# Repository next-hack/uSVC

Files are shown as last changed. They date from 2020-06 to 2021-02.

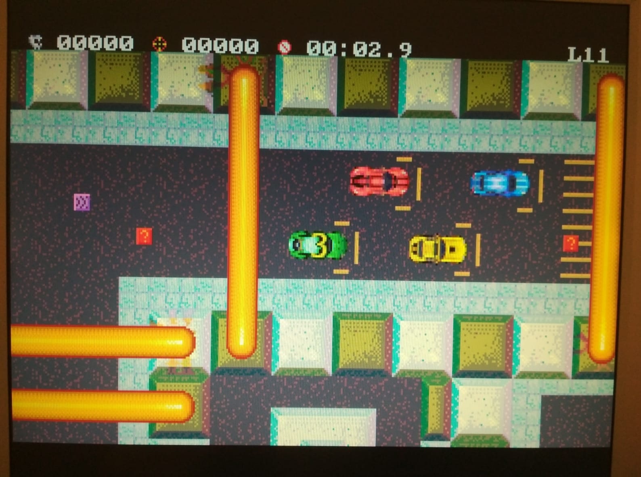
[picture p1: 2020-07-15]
images/Fairplay Race 3.jpg

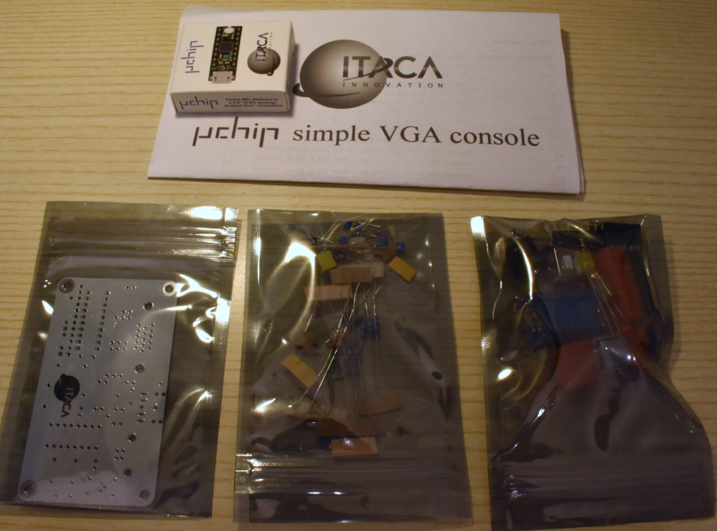
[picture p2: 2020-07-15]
images/Kit contents.png

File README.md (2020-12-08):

# uSVC
uChip Simple VGA Console
An open source, easy to build retro game console!

This project is a very simple VGA console, based on uChip. Games are loaded from the SD card, and you can use standard keyboards or gamepads.

The console is made of few, easy to find and easy to solder components. There is only one SMD component: the micro-SD card reader.

The ATSAMD21 (A 48 MHz Cortex M0+) generates the VGA and audio signals, and provides up to 256 simultaneous colors. There are 3 video modes:
- Bitmapped Mode
- 8 bpp tiled mode
- 4 bpp tiled mode.

Each mode has its own peculiarity. For more information, visit next-hack.com!

You might also want to take a look at:

- The game editor source code: https://github.com/next-hack/uChipGameMapEditor
- Redballs, a Worms-like game: https://github.com/next-hack/uSVC_Redballs
- Fairplay race: https://github.com/next-hack/uSVC_Fairplay-race
- uSVC Tetris: https://github.com/next-hack/uSVC_Tetris

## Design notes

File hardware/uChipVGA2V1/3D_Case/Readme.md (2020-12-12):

3D Case designed by [Stefano Rubini](https://dreamdesigndevelop3d.webnode.it/english/).
Available ".stl" files are:
- Top:     "#55 case no standoff top.stl"
- Bottom:  "#55 case no standoff bottom.stl"

Available ".step" files are:
- Assembled: "case uChipVGA v55.step"

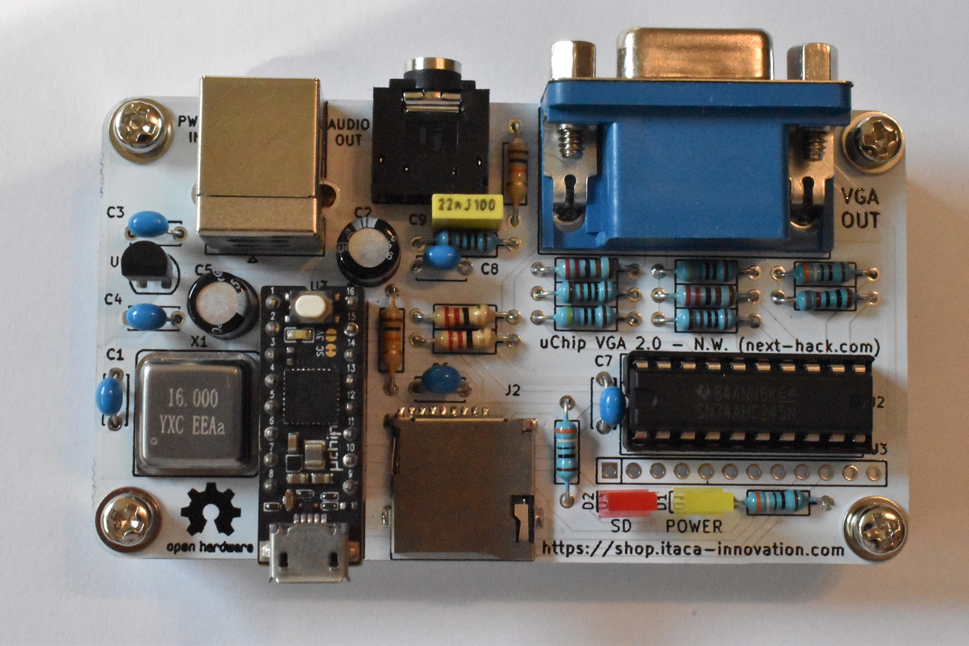
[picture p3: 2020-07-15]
images/uSVC-reduced.jpg

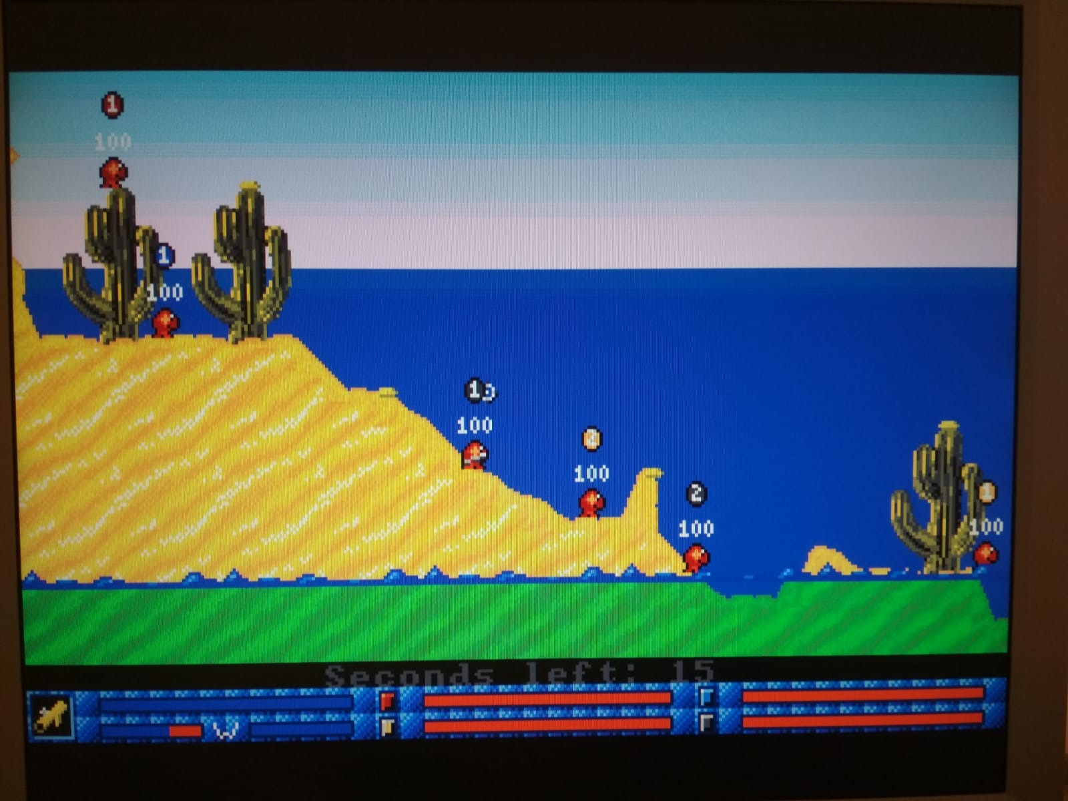
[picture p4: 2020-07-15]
images/redballs3.png

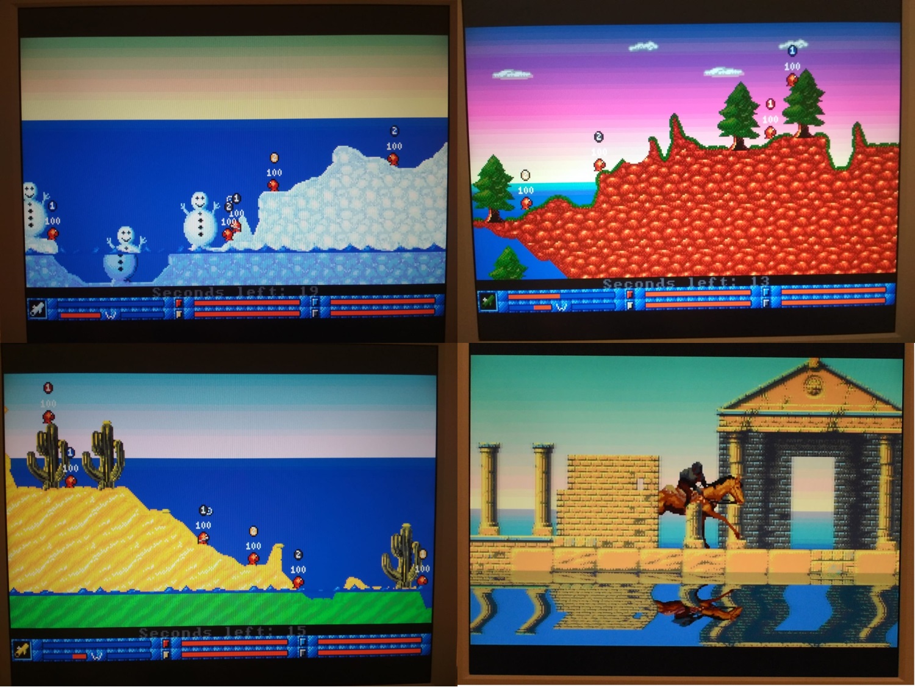
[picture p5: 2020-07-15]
images/4bpp combined.jpg

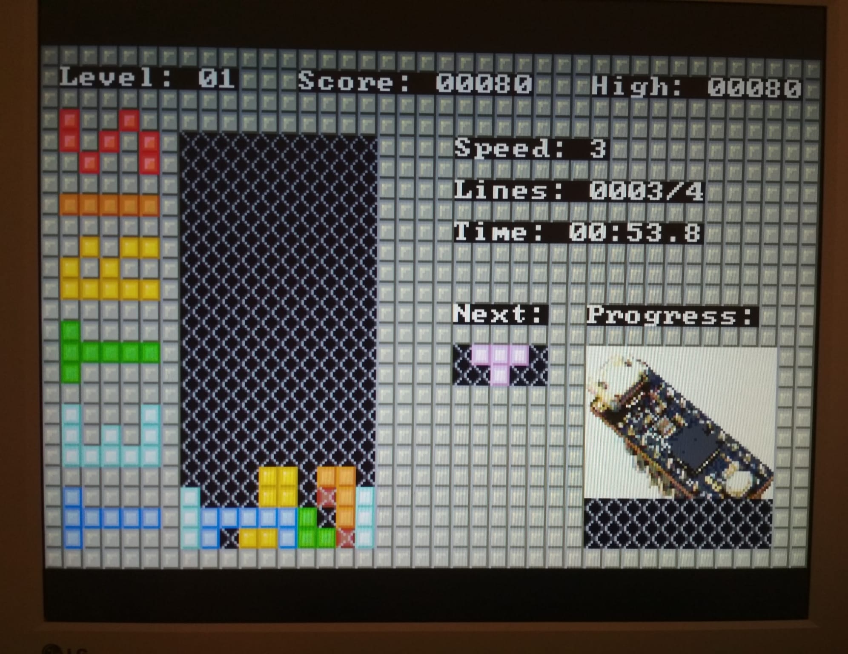
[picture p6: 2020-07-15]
images/tetris.jpg

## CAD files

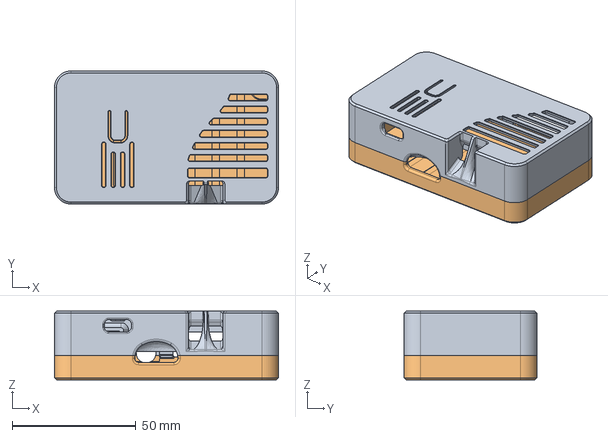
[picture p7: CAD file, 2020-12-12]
hardware/uChipVGA2V1/3D_Case/case uChipVGA v55.step
90.7 x 53.9 x 27.9 mm

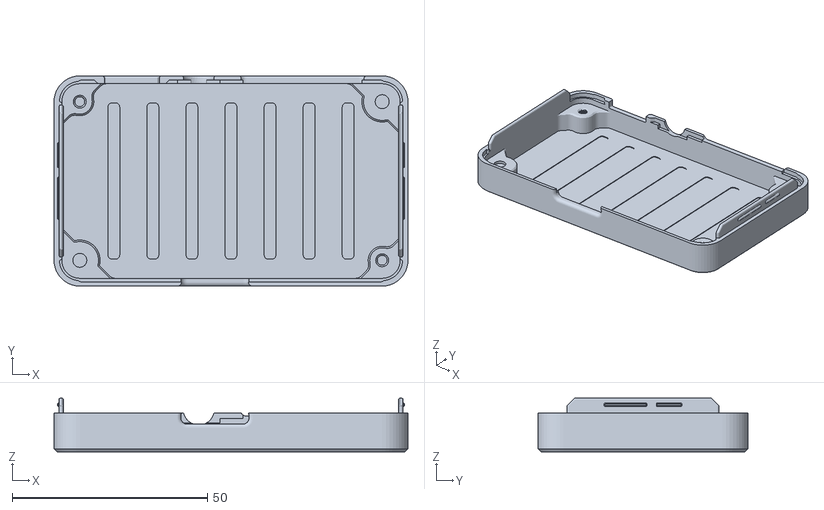
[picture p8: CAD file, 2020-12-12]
hardware/uChipVGA2V1/3D_Case/#55 case no standoff bottom.stl
90.7 x 53.9 x 13.8

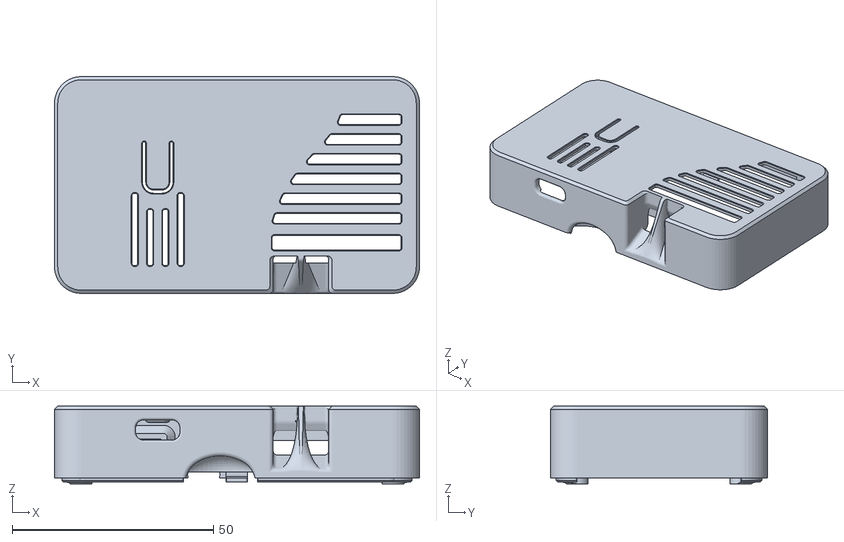
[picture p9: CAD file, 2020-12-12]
hardware/uChipVGA2V1/3D_Case/#55 case no standoff top.stl
90.7 x 53.9 x 19.3

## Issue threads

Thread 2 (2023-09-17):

uSVC emulator

danboid, 2023-09-17:
Hi next-hack!

The uSVC is a very cool and interesting project! I think its the most complete and promising potential successor to the Uzebox that I've seen yet although I can't see it gaining much popularity without three more things:

1- An emulator

The uSVC needs more games to attract users and they won't come unless you make it easier to write games for it and the best thing you could do to help potential devs write games for the uSVC is release an emulator.  Ideally it would be open source and run on all the popular platforms.

2 - User forums and wiki

I've not seen any forums for the uSVC. The Uzebox forums and wiki have been key to it being the pretty much only open source console with an established community.

3 - PROMOTION

I see the uSVC borrows the Uzebox sound engine? Why have non of you visited the Uzebox forums to tell us about the uSVC? The Uzebox forum has a dedicated sub-forum for other open source consoles so I created a thread about the uSVC:

https://uzebox.org/forums/viewtopic.php?t=11330

I'm not good enough at programming to write an emulator of the uSVC but I'd be wlling to have a go at writing a game for it if someone writes an emulator.

danboid, 2023-09-17:
I watched Adrian Black's video on the uSVC.

https://www.youtube.com/watch?v=G7oAJZahPbo

It seems he was unable to get his iMac USB keyboard working with the uSVC because it has an integrated USB hub.

I would want to use a USB hub with the uSVC to connect more than one joypad, or a joypad and a keyboard etc. Does the uSVC support USB hubs?

next-hack, 2023-09-19:
Hi Dan,Sorry for late reply.USVC is using a SAM D21, which does not support hubs with low speed devices connected to it (cannot issue PRE packet id). Since the majority of gamepads and keyboards are low speed, I have dropped USB hub support, and multiplayer as well.Best regards,NicolaIl 17 set 2023 06:52, Dan MacDonald ***@***.***> ha scritto:
I watched Adrian Black's video on the uSVC.
https://www.youtube.com/watch?v=G7oAJZahPbo
It seems he was unable to get his iMac USB keyboard working with the uSVC because it has an integrated USB hub.
I would want to use a USB hub with the uSVC to connect more than one joypad, or a joypad and a keyboard etc. Does the uSVC support USB hubs?

—Reply to this email directly, view it on GitHub, or unsubscribe.You are receiving this because you are subscribed to this thread.Message ID: ***@***.***>
Il 17 set 2023 06:52, Dan MacDonald ***@***.***> ha scritto:
I watched Adrian Black's video on the uSVC.
https://www.youtube.com/watch?v=G7oAJZahPbo
It seems he was unable to get his iMac USB keyboard working with the uSVC because it has an integrated USB hub.
I would want to use a USB hub with the uSVC to connect more than one joypad, or a joypad and a keyboard etc. Does the uSVC support USB hubs?

—Reply to this email directly, view it on GitHub, or unsubscribe.You are receiving this because you are subscribed to this thread.Message ID: ***@***.***>
Il 17 set 2023 06:52, Dan MacDonald ***@***.***> ha scritto:
I watched Adrian Black's video on the uSVC.
https://www.youtube.com/watch?v=G7oAJZahPbo
It seems he was unable to get his iMac USB keyboard working with the uSVC because it has an integrated USB hub.
I would want to use a USB hub with the uSVC to connect more than one joypad, or a joypad and a keyboard etc. Does the uSVC support USB hubs?

—Reply to this email directly, view it on GitHub, or unsubscribe.You are receiving this because you are subscribed to this thread.Message ID: ***@***.***>
Il 17 set 2023 06:52, Dan MacDonald ***@***.***> ha scritto:
I watched Adrian Black's video on the uSVC.
https://www.youtube.com/watch?v=G7oAJZahPbo
It seems he was unable to get his iMac USB keyboard working with the uSVC because it has an integrated USB hub.
I would want to use a USB hub with the uSVC to connect more than one joypad, or a joypad and a keyboard etc. Does the uSVC support USB hubs?

—Reply to this email directly, view it on GitHub, or unsubscribe.You are receiving this because you are subscribed to this thread.Message ID: ***@***.***>
Il 17 set 2023 06:52, Dan MacDonald ***@***.***> ha scritto:
I watched Adrian Black's video on the uSVC.
https://www.youtube.com/watch?v=G7oAJZahPbo
It seems he was unable to get his iMac USB keyboard working with the uSVC because it has an integrated USB hub.
I would want to use a USB hub with the uSVC to connect more than one joypad, or a joypad and a keyboard etc. Does the uSVC support USB hubs?

—Reply to this email directly, view it on GitHub, or unsubscribe.You are receiving this because you are subscribed to this thread.Message ID: ***@***.***>

danboid, 2023-09-19:
Hi Next-hack

That's unfortunate that the uSVC doesn't support USB hubs. That means that its currently only possible to connect one joypad (or keyboard) to the uSVC right?

Is there any chance of the uSVC getting Bluetooth support? That could allow for wireless keyboard support and more than one joypad.

Thanks

next-hack, 2023-09-23:
Hi Dan,Yes, only one controller.I found that some wireless controllers are full-speed, so hub are supported on this case, but since this is a really limited use case, I did not include the code.Cheers!Il 19 set 2023 14:00, Dan MacDonald ***@***.***> ha scritto:
Hi Next-hack
That's unfortunate that the uSVC doesn't support USB hubs. That means that its currently only possible to connect one joypad (or keyboard) to the uSVC right?
Is there any chance of the uSVC getting Bluetooth support? That could allow for wireless keyboard support and more than one joypad.
Thanks

—Reply to this email directly, view it on GitHub, or unsubscribe.You are receiving this because you commented.Message ID: ***@***.***>

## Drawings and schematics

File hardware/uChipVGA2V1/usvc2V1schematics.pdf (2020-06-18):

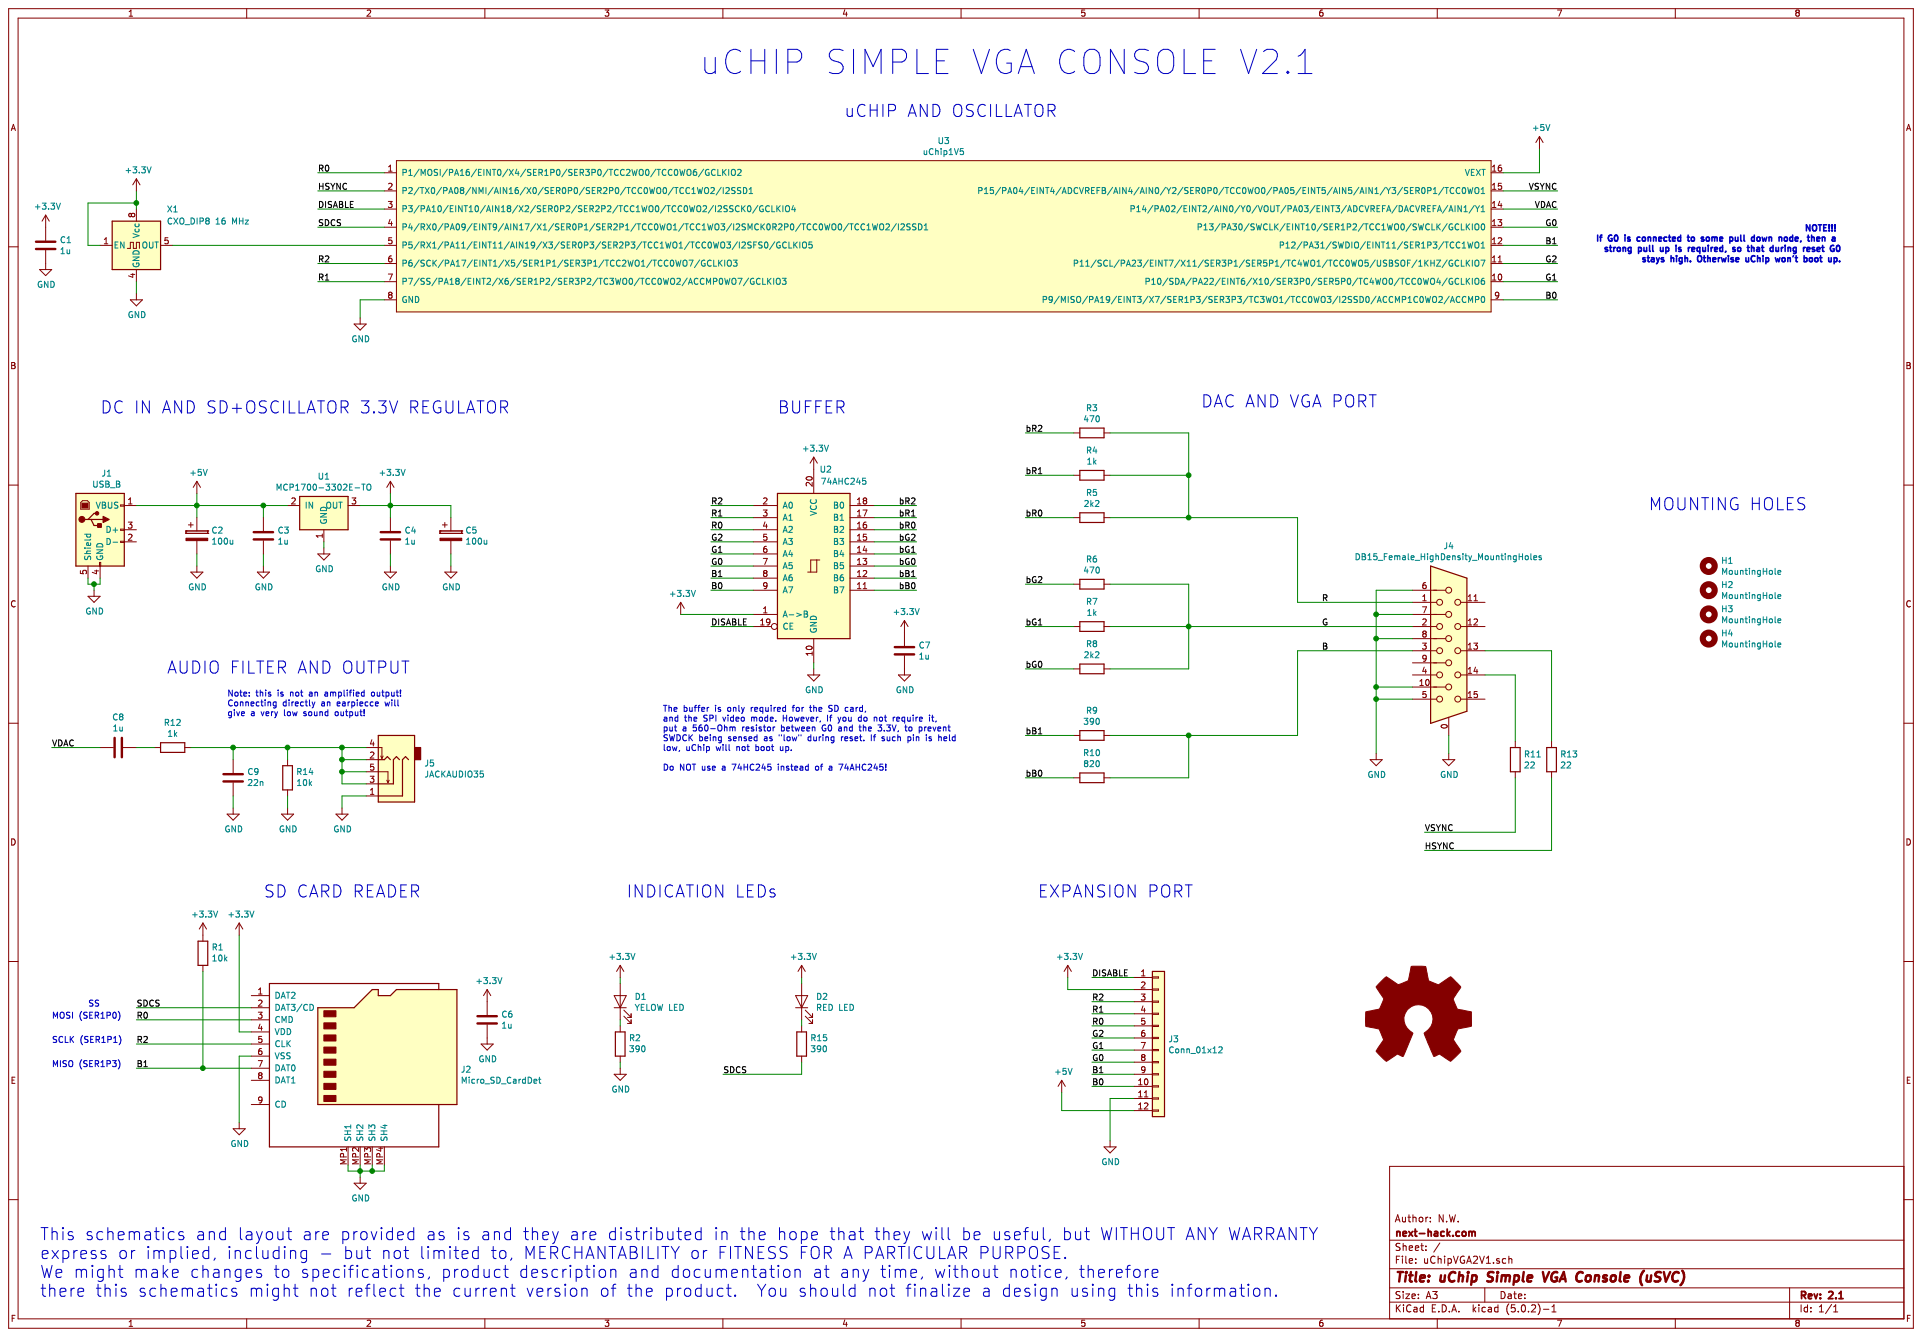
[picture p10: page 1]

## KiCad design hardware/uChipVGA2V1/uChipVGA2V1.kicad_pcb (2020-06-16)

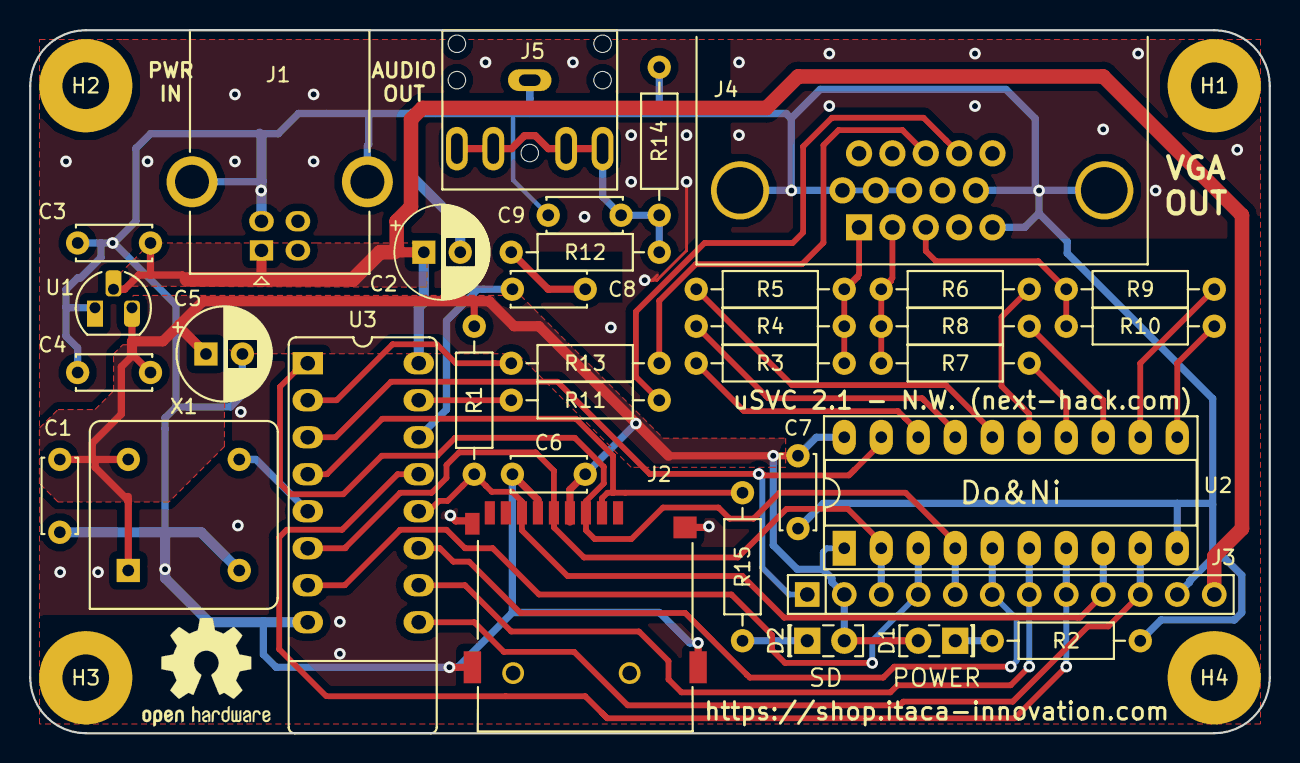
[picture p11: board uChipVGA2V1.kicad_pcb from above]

Board: 2 copper layers, 85.1 x 48.3 mm, 40 parts (0 on the bottom side), 34 nets.

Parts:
C1, C3, C4, C6, C7, C8: 1u; C_Disc_D5.0mm_W2.5mm_P5.00mm
C2, C5: 100u; CP_Radial_D6.3mm_P2.50mm
C9: 22n; C_Disc_D5.0mm_W2.5mm_P5.00mm
D1, D2: LED; LED_Rectangular_W5.0mm_H2.0mm
H1, H2, H3, H4: MountingHole; MountingHole_3.2mm_M3_Pad
J1: USB_B; USB_B_OST_USB-B1HSxx_Horizontal
J2: Micro_SD_CardDet; HYC77TF09200
J3: Conn_01x12; PinHeader_1x12_P2.54mm_Vertical
J4: DB15_Female_HighDensity_MountingHoles; DSUB-15-HD_Female_Horizontal_P2.29x2.54mm_EdgePinOffset8.55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
J5: JACKAUDIO35; SJ-3525NG
LOGO1: Logo_Open_Hardware_Large; OSHW-Logo2_9.8x8mm_SilkScreen
R1, R14: 10k; R_Axial_DIN0207_L6.3mm_D2.5mm_P10.16mm_Horizontal
R2, R9, R15: 390; R_Axial_DIN0207_L6.3mm_D2.5mm_P10.16mm_Horizontal
R3, R6: 470; R_Axial_DIN0207_L6.3mm_D2.5mm_P10.16mm_Horizontal
R4, R7, R12: 1k; R_Axial_DIN0207_L6.3mm_D2.5mm_P10.16mm_Horizontal
R5, R8: 2k2; R_Axial_DIN0207_L6.3mm_D2.5mm_P10.16mm_Horizontal
R10: 820; R_Axial_DIN0207_L6.3mm_D2.5mm_P10.16mm_Horizontal
R11, R13: 22; R_Axial_DIN0207_L6.3mm_D2.5mm_P10.16mm_Horizontal
U1: MCP1700-3302E-TO; TO-92L_HandSolder
U2: 74AHC245; DIP-20_W7.62mm_Socket_LongPads
U3: uChip1V5_LargePads
X1: CXO_DIP8; Oscillator_DIP-8

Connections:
+3V3: C1.1, C4.1, C5.1, C6.1, C7.1, D1.2, D2.2, J2.4, J3.2, R1.2, U1.3, U2.1, U2.20, X1.1, X1.8
+5V: C2.1, C3.1, J1.1, J3.12, U1.2, U3.16
/B: J4.3, R9.1, R10.1
/B0: J3.10, U2.9, U3.9
/B1: J2.7, J3.9, R1.1, U2.8, U3.12
/DISABLE: J3.1, U2.19, U3.3
/G: J4.2, R6.1, R7.1, R8.1
/G0: J3.8, U2.7, U3.13
/G1: J3.7, U2.6, U3.10
/G2: J3.6, U2.5, U3.11
/HSYNC: R13.2, U3.2
/R: J4.1, R3.1, R4.1, R5.1
/R0: J2.3, J3.5, U2.4, U3.1
/R1: J3.4, U2.3, U3.7
/R2: J2.5, J3.3, U2.2, U3.6
/SDCS: J2.2, R15.1, U3.4
/VDAC: C8.2, U3.14
/VSYNC: R11.2, U3.15
/bB0: R10.2, U2.11
/bB1: R9.2, U2.12
/bG0: R8.2, U2.13
/bG1: R7.2, U2.14
/bG2: R6.2, U2.15
/bR0: R5.2, U2.16
/bR1: R4.2, U2.17
/bR2: R3.2, U2.18
GND: C1.2, C2.2, C3.2, C4.2, C5.2, C6.2, C7.2, C9.1, J1.4, J1.5, J2.6, J2.MP1, J2.MP2, J2.MP3, J2.MP4, J3.11, J4.0, J4.5, J4.6, J4.7, J4.8, J4.10, J5.1, R2.1, R14.1, U1.1, U2.10, U3.8, X1.4
unnamed: C8.1, R12.2
unnamed: C9.2, J5.2, J5.3, J5.4, J5.5, R12.1, R14.2
unnamed: D1.1, R2.2
unnamed: D2.1, R15.2
unnamed: J4.13, R13.1
unnamed: J4.14, R11.1
unnamed: U3.5, X1.5

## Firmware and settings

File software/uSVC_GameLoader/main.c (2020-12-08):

/*	USVC Game Loader and libraries
*
 *  Copyright 2019-2020 Nicola Wrachien (next-hack.com)
 *
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
 *  tl;dr 
 *  Do whatever you want, this program is free! Though we won't 
 *  reject donations https://next-hack.com/index.php/donate/ :) 
 *
 * main.c/h for bootloader. Compile this with "optimize for size" switch! 
 *
 */
#include "main.h"
#define GAME_START_ADDRESS 0x6000
#define PREVIEW_SIZE_X 12
#define PREVIEW_SIZE_Y 9
#define PREVIEW_START_Y 6
#define PREVIEW_START_X (40 - 14)
#define NUMBER_OF_SECTORS_PER_IMAGE ((PREVIEW_SIZE_X * PREVIEW_SIZE_Y * TILE_SIZE_X * TILE_SIZE_Y + 511)/512)
#define VERSION "0.1"
extern uint32_t *_sfixed;
#define NUMBER_OF_CHARACTERS (128 + 6 - ' ')
uint8_t selectedFileName[13];  // 8.3+null
uint16_t keyBuffer[6] = {0, 0, 0, 0, 0, 0};
#define NO_USB 0			// 1 for testing without USB
#include <stdlib.h>
// we need a vector table in ram, because during erase and programming, any access to flash would stall the CMO+ so video would not  be generated.
void* ramVectorTable[16+44] __attribute__((__aligned__(256)));
const uint8_t colors[] = 
{
	COLOR_TORGB332(7, 5, 1),  // regions that won't be programmed
	COLOR_TORGB332(7, 5, 1),  // regions that won't be programmed
	COLOR_TORGB332( 0, 5, 3), // erased region
	COLOR_TORGB332( 0, 5, 3), // erased region
	COLOR_TORGB332( 1, 5, 1), //   programmed region
	COLOR_TORGB332( 1, 5, 1)
};  //  programmed region

// coordinates for printing the game info. 255 = do not print.
typedef struct
{
	uint8_t x;
	uint8_t y;
} xy_t;
const xy_t coordinates[] =
{
	{255, 0}, // short title
	{25, 1},  // title 1
	{25, 2},  // title 2
	{25, 3},  // title 3
	{25, 4},  // title 4
	{25, 16},  // desc 1
	{25, 17},  // desc 2
	{25, 18},  // desc 3
	{25, 19},  // desc 4
	{25 ,22},  // author 1
	{25 ,23},  // author 2
	{25, 21},  // date
	{25 + 9, 21},  // version
};
// 
#define FPB 5.5
const uint8_t startSound[] =
{
	0, BL_SET_ENV_DATA, 0, 1,
	57, BL_SET_ENV_DATA, 0xFF,	-4,
	//
	5,	BL_PLAY_NOTE,  BL_NOTE(BL_NOTE_B5),
	55, BL_PLAY_NOTE,   BL_NOTE(BL_NOTE_B5),
	22, BL_PLAY_NOTE,   BL_NOTE(BL_NOTE_B5),
	11, BL_PLAY_NOTE,   BL_NOTE(BL_NOTE_A5),
	22, BL_PLAY_NOTE,   BL_NOTE(BL_NOTE_A5),
	22, BL_PLAY_NOTE,   BL_NOTE(BL_NOTE_CS6),
	11, BL_PLAY_NOTE,   BL_NOTE(BL_NOTE_D6),
	11, BL_PLAY_NOTE,   BL_NOTE(BL_NOTE_CS6),
	11, BL_PLAY_NOTE,   BL_NOTE(BL_NOTE_A5),
	11, BL_PLAY_NOTE,   BL_NOTE(BL_NOTE_B5),
	55, BL_PLAY_NOTE,	0,		0,	
	255  // sound end
};		
const uint8_t menuSound[] =
{
	0, BL_SET_ENV_DATA, 255, 0,
	0,	BL_PLAY_NOTE,  BL_NOTE(BL_NOTE_C7),
	8, BL_SET_ENV_DATA, 0, 0,
	0, BL_SET_ENV_DATA, 255, 0,
	0,	BL_PLAY_NOTE,  BL_NOTE(BL_NOTE_C7),
	8, BL_SET_ENV_DATA, 0, 0,
	255  // sound end
};
FATFS fs;
uint8_t numberOfPages = 1;
static uint16_t g_frame = 0;	
#define UPPER_CASE_ONLY 0	
#define FILES_PER_PAGE 8
uint8_t fileNames[FILES_PER_PAGE][13];
uint16_t numberOfFiles;
uint16_t currentPage = 0;
int16_t selectedFile = 0 ;
uint32_t binChecksum = 0;
uint32_t binLength = 0;
const char usvcFileExt [] = "USC";
uint8_t fileBuffer[512];
#define PAGE_SIZE 64
void printLine (const char * text, int8_t col, uint8_t row)
{
	const uint8_t *pText = (uint8_t*) text;
	for (uint8_t c = col; c < 40 && *pText != 0; c++)
	{
		#if UPPER_CASE_ONLY
			uint8_t ch;
			ch = *pText++;
			if (ch >= 'a' && ch <= 'z')
				ch = ch - 'a' + 'A';
			vram[ row *  VRAMX + c] =  charTileSet + ch;

		#else
			int8_t character = *pText++ - ' ';
//			if (character < 0)
//				character = 0;
			vram[ row *  VRAMX + c] =  character;
		#endif
	}
}
#if GFX_MODE == TILE_MODE_BOOT && DEGUB_BOOTLOADER
void addLineAtBottom(char *text, uint16_t fgColor, uint16_t bkgColor)
{
	for (int y = 0; y < 24; y++)
	{
		for (int x = 0; x < 40; x++)
		{
			vram[y * 40 + x] = vram[(y + 1) * 40 + x];
		}	
	}
	for (int x = 0; x < 40; x++)
	{
		vram[24 * 40 + x] = 0;
	}
	printLine(text, 0, 24);
}
void debug(uint32_t i, uint8_t row)
{
	uint8_t buf[32];
	snprintf(buf,32,"VAL: 0X%08X",i);
	printLine(buf,0,row);
}
#endif
uint16_t listFiles (uint16_t filesToIgnore, uint8_t scanOnly)
{
	FRESULT res;
	DIR dir;
	FILINFO fno;  
	//uint8_t dirBuffer[512];
	//res = pf_opendir(&dir, "", dirBuffer, sizeof(dirBuffer) == 512); 
	// Updated 15/05/2020. Since we do not read files + list dirs at the same time, to prevent using too much stack space, we can use fileBuffer
	res = pf_opendir(&dir, "", fileBuffer, sizeof(fileBuffer) == 512);                     
	uint16_t u = 0;
	if (res == FR_OK) 
	{
		while (u < filesToIgnore + FILES_PER_PAGE || scanOnly) 
		{
//			res = pf_readdir(&dir, &fno, dirBuffer,  sizeof(dirBuffer) == 512);                   // Read a directory item 
			res = pf_readdir(&dir, &fno, fileBuffer,  sizeof(fileBuffer) == 512);                   // Read a directory item 
			if (res != FR_OK || fno.fname[0] == 0) 
				break;  // Break on error or end of dir 
			if (!(fno.fattrib & AM_DIR)) 
			{	
				int n = 0;
				uint8_t  match = 1;
				while (fno.fname[n] != '.' && fno.fname[n] != 0)
					n++;
				for (int m = 0; m < 3; m++)
				{
					uint8_t c = fno.fname[n + 1 + m];
					if (c >= 'a' && c <= 'z')
						c = c - ('a' - 'A');
					if (c != usvcFileExt[m])
						match = 0;
				}				
				if (match)
				{
					if (u >= filesToIgnore && !scanOnly)
					{
						// copy file name
						memcpy(fileNames[u - filesToIgnore], fno.fname, 13);
					}
					u++;					
				}
			}
		}
	}
	// now that all the files are scanned, try to open the selected one.
	return u;
}
void goToGame()
{
	// 	uint32_t app_start_address, tmpReg, zeroReg;
	// We need to disable all the interrupts we might have initialized.
	SysTick->CTRL = 0;
// 	NVIC_DisableIRQ( TCC1_IRQn ) ;
// 	NVIC_DisableIRQ( TCC0_IRQn ) ;
// 	NVIC_DisableIRQ( EVSYS_IRQn ) ;
    NVIC->ICER[0U] = ((1 << TCC1_IRQn) | (1 << TCC0_IRQn) | (1 << EVSYS_IRQn)) ;		// disable ALL the interrupts.
    __DSB();
    __ISB();	
//     NVIC->ICER[0U] = ((1 << TCC1_IRQn) | (1 << TCC0_IRQn) | (1 << EVSYS_IRQn)) ;		// disable ALL the interrupts.

	// WARNING! IT IS VERY IMPORTANT TO STOP THE USB BEFORE JUMPING TO THE APPLICATION!!!
	USB->HOST.CTRLA.reg = USB_CTRLA_SWRST;
	// NOTE: THE FOLLOWING SYNC WAIT IS MANDATORY!!!!
	while (USB->HOST.SYNCBUSY.bit.SWRST);
	uint32_t dummy;
	uint32_t address = GAME_START_ADDRESS;
	asm volatile
	( 
		"LDMIA %[address]!, {%[tmp]}\n\t"  // load stack pointer
		"MOV SP, %[tmp]\n\t"			   // set
		"LDMIA %[address]!, {%[tmp]}\n\t"  // load application address
		"BX %[tmp]\n\t"				   // jump
		: [tmp] "=&r" (dummy) 
		: [address] "r" (address)
	);
}
void unpackTiles(const uint8_t *buffer, uint16_t howManyBytes, uint8_t position)
{
	// tiles are stored in 8-bit format. Here we unpack them, having care also of choosing the correct values of the other signals.
	uint16_t *dest = tiles[position];
	for (int i = 0; i < howManyBytes; i++)
	{
		uint16_t colorSignal = ((*buffer++ * 1025) & 0b1100000011001111) | (1 << 12)  | (1 << 9);
		*dest++ = colorSignal;
	}
}
RAMFUNC void erase(uint32_t startAddr, uint32_t endAddr)
{
	// NOTE! in this function we must avoid touching the flash during erase, otherwise a stall will occur.
	#if AUDIO_ENGINE_ON_VBLANK_INTERRUPT
		NVIC_DisableIRQ( TCC0_IRQn );		// this will disable audio sound engine. Mandatory, to avoid accessing flash!
	#endif
	while (startAddr < endAddr)
	{	
		NVMCTRL->ADDR.reg = startAddr / 2;
		NVMCTRL->CTRLA.reg = NVMCTRL_CTRLA_CMDEX_KEY | NVMCTRL_CTRLA_CMD_ER;
		while (NVMCTRL->INTFLAG.bit.READY == 0);
		uint8_t x = 3 + (startAddr >> 13);
		vram[x + 12 * VRAMX] = NUMBER_OF_CHARACTERS;
		vram[x + 13 * VRAMX] = NUMBER_OF_CHARACTERS + 1;		
		startAddr += PAGE_SIZE * 4; // point to next row
	}
	#if AUDIO_ENGINE_ON_VBLANK_INTERRUPT
		NVIC_EnableIRQ( TCC0_IRQn ) ;
	#endif
}
RAMFUNC void writeToFlash(uint8_t *buffer, uint32_t addr, uint16_t size)
{
	// NOTE! in this function we must avoid touching the flash during write, otherwise a stall will occur.
	#if AUDIO_ENGINE_ON_VBLANK_INTERRUPT
		NVIC_DisableIRQ( TCC0_IRQn );		// this will disable audio sound engine. Mandatory, to avoid accessing flash!	
	#endif
	uint32_t *src_addr = (uint32_t *) buffer;
	uint32_t *dst_addr = (uint32_t*)addr;
	// convert to word size
	size = size / 4;
	// Do writes in pages. Note manual page write is enabled at startup!
	while (size)
	{
		// Execute "PBC" Page Buffer Clear
		NVMCTRL->CTRLA.reg = NVMCTRL_CTRLA_CMDEX_KEY | NVMCTRL_CTRLA_CMD_PBC;
		while (NVMCTRL->INTFLAG.bit.READY == 0);
		uint32_t i;
		for (i=0; i < (PAGE_SIZE/4) && i < size; i++)
		{
			//dst_addr[i] = src_addr[i];
			*dst_addr++ = *src_addr++;
		}
		// Execute "WP" Write Page
		NVMCTRL->CTRLA.reg = NVMCTRL_CTRLA_CMDEX_KEY | NVMCTRL_CTRLA_CMD_WP;
		while (NVMCTRL->INTFLAG.bit.READY == 0);
		// Advance to next page
// 		dst_addr += i;
// 		src_addr += i;
		size     -= i;
	}
	#if AUDIO_ENGINE_ON_VBLANK_INTERRUPT
		NVIC_EnableIRQ( TCC0_IRQn ) ;	
	#endif
}

void unpackLogoTiles(uint8_t c, uint8_t pos)
{
	// c = color set
	uint16_t *d = &tiles[NUMBER_OF_CHARACTERS + 1 + (MAXTILEINDEX + 1) * pos][0];
	const uint8_t *p = &tileData[0][0];
	for (int i = 0; i < MAXTILEINDEX * 16; i++)
	{   // note! Tile 0 is empty, so we won't store it! It's already initialized to 0!
		uint8_t byte = *p++;
		for (int j = 0; j < 4; j++)
		{
			uint8_t color = tilePalette[((byte >> (2 * j)) & 0x3) + 4 * c];
			uint16_t colorSignal = ((color * 1025) & 0b1100000011001111) | (1 << 12)  | (1 << 9);
			*d++ = colorSignal;
		}
	}		
}
void drawLogo(uint8_t xs, uint8_t ys, uint8_t colorSet)
{
	for (uint16_t y = 0; y < MAPSIZEY_LOGO; y++)
	{
		for (uint16_t  x = 0; x < MAPSIZEX_LOGO/2; x++)
		{
			uint8_t biTile = logoMap[ x + MAPSIZEX_LOGO/2 * y];
			vram[xs + 2 * x + (y + ys) * VRAMX] = (0xF & biTile) + NUMBER_OF_CHARACTERS + (MAXTILEINDEX + 1) * colorSet;
			vram[xs + 2 * x + 1 + (y + ys) * VRAMX] = (biTile >> 4) + NUMBER_OF_CHARACTERS + (MAXTILEINDEX + 1) * colorSet;
		}		
	}
}
uint16_t reasonablyFastUint16ToArray(uint16_t  n, uint8_t *array /*, uint8_t showLeadingZeroes*/)
{
	int number = n;
	const int multArray[] = {10000, 1000, 100, 10, 1};
	uint8_t nonZero = 0 /*showLeadingZeroes*/;
	int mult;
	int digit;
	int digitNumber = 0;
	for (int i = 0; i < sizeof(multArray)/sizeof(multArray[0]); i++)
	{
		mult = multArray[i];
		for (digit = 0; digit < 10 && number >= 0; digit++)
		{
			number -= mult;
		}
		if (digit > 1 || i == sizeof(multArray)/sizeof(multArray[0]) - 1)
			nonZero = 1;
		number += mult;
		if (nonZero)
			array[digitNumber++] = digit - 1 + (nonZero ? '0' : ' ');
	}
	array[digitNumber] = 0;
	return digitNumber;
}
void drawMenu(uint8_t page, uint8_t selectedItem, uint8_t pageChanged)
{
	// If we were in a time-constrained environment (e.g. a game) we would not redraw everytime everything. 
	// In the bootloader, instead, space is a premium, therefore instead of choosing where to draw (to avoid time consuming operations)
	// we just crear everything and redraw.
	// clear vram 
	if (pageChanged)
	{
		memset(fileNames, 0, sizeof(fileNames));
		listFiles(page * FILES_PER_PAGE, 0);
	}
	// clear screen
	memset(vram,0, sizeof(vram));
	// draw menu bars
	for (int x = 0; x < 24; x++)
	{
		vram[x + 3 * VRAMX] = 127 - 32;
		vram[x + 21 * VRAMX] = 127 - 32;
	}
	for (int y = 0; y < 25; y++)
	{
		vram[23 + y * VRAMX] = 127 - 32;
	}	
	printLine("uSVC game loader v" VERSION, 1, 1);	
	// print file names and the selected one
	for (int y = 0; y < FILES_PER_PAGE; y++)
	{
		printLine((char*)fileNames[y],3,  5 + y * 2);
		if (y == selectedItem)
			vram[1 + (y * 2 + 5) * VRAMX] =  '>' - ' ';
	}
	uint8_t buffer[6];
	printLine("Page ",1, 23);
	int n = reasonablyFastUint16ToArray(page + 1, buffer);
	printLine((char*)buffer,6, 23);
	vram[23 * VRAMX + 6 + n] = '/' - ' ';
	n += reasonablyFastUint16ToArray(numberOfPages, buffer);
	printLine((char*) buffer,6 + n, 23);		
	// 15-05-2020. Since when we read the file, we do not need a dirbuffer, we will use the single global file buffer, to prevent stack overflow
	uint8_t res;
	res = pf_open((char*)fileNames[selectedItem], fileBuffer,sizeof(fileBuffer) == 512);
	// first read the first sector to print all the information
	UINT br;
	pf_read(fileBuffer, 512, &br);
	if (br == 512)
	{
		// get length and checksum. tHese are already stored in little endian format.
		binChecksum = *((uint32_t *) &fileBuffer[4]);
		binLength = *((uint32_t *) &fileBuffer[8]);
		// coordinates to quickly draw: 255 in x => do not print
		for (int i = 0; i < sizeof(coordinates) / sizeof(xy_t); i++)
		{
			if (coordinates[i].x != 255)
				printLine((const char*)&fileBuffer[(i + 1) * 32], coordinates[i].x, coordinates[i].y);
		}	
	}
	else 
		res = 1;
	// now read everything
//	int32_t read = 0;	
	for (int i = 0; !res && i < NUMBER_OF_SECTORS_PER_IMAGE; i++)
	{
		res |= pf_read(fileBuffer, 512, &br);
		if (br == 512)
		{
			// tiles for the preview are saved in a rgb USVC format. We need to unpack them
			unpackTiles(fileBuffer, i == 13 ? 256 : 512, NUMBER_OF_CHARACTERS + i * 8);
		}
//		read+=br;
	}
	if (res)
	{
		binLength = 0;
		printLine("File Error",12, 23);
	}	
	// restore the zone where preview should appear.
	uint8_t tileN = NUMBER_OF_CHARACTERS;
	for (int y = PREVIEW_START_Y; y < PREVIEW_START_Y + PREVIEW_SIZE_Y; y++)
	{
		for (int x = PREVIEW_START_X; x < PREVIEW_START_X + PREVIEW_SIZE_X; x++)
		{
			vram[y * VRAMX + x] = tileN;
			tileN++;
		}
	}	
}
 int main(void) 
{	
	// copy vector table in ram. Important! When erasing or writing is performed NO flash access is possible 
	// (otherwise the bus - and consequently, the CortexM0+ will stall for several hundreds of microseconds, and the video signal will get corrupted.)
	uint8_t * pSrc = (void *) &_sfixed;
	memcpy (ramVectorTable, pSrc, sizeof(ramVectorTable));
	SCB->VTOR = ((uint32_t) ramVectorTable & SCB_VTOR_TBLOFF_Msk);
	initUsvc(NULL);	
	//
	// create the characters
	for (int c = ' '; c < 128 + 6; c++)
		putCharInTile(NULL, c, c != 127 ? 0xFF : COLOR_TORGB332( 7, 5, 1), 0, 0, (uint8_t*) tiles[c - ' '], 0);
	// unpack the 2-bit logo tiles with two different color sets
	for (int i = 0; i < 2; i++)
		unpackLogoTiles(i, i);
	memset(rowRemapTable, 27 * TILE_SIZE_Y - 1, 200);		
	drawLogo(3, 0, 1);
	drawLogo(3, 13, 0);
	bootloaderStartSong(startSound);
	uint8_t logoAnim = 0;
	uint16_t oldKey = 0;
	// mount the fat file system and read the number of files.	
	pf_mount(&fs);
	numberOfFiles = listFiles(0,1);
	numberOfPages = (numberOfFiles + FILES_PER_PAGE - 1) / FILES_PER_PAGE;
	while (1)
	{
		waitForVerticalBlank();
#if !AUDIO_ENGINE_ON_VBLANK_INTERRUPT
	#if AUDIO_ENABLED
			soundEngine();			// called here to be sure it will be called at an almost constant 		
	#elif USE_BL_AUDIO
		bootloaderSoundEngine();
	#endif
#endif
		if (g_frame > 125) // wait till the monitor gets in synch
		{
			if (logoAnim < 13 * TILESIZEY)
			{
			    // we want the logo (which is between 0 and 13 * TILESIZEY to be placed about in the center, i.e. starting from 6 * TILESIZEY
				for (uint8_t y = 0; y < 13 * TILESIZEY - logoAnim; y++)
					rowRemapTable[6 * TILE_SIZE_Y + y] = 13 * TILESIZEY - 1 - logoAnim;
				rowRemapTable[6 * TILE_SIZE_Y + 13 * TILESIZEY - logoAnim] = 26 * TILESIZEY - logoAnim;				
			}
			else if (logoAnim ==  13 * TILESIZEY)
			{
				rowRemapTable[6 * TILE_SIZE_Y + 13 * TILESIZEY - logoAnim] = 26 * TILESIZEY - logoAnim;	
				printLine("Another madness from next-hack!", 6, 11 + 13);
			}
			else if (logoAnim < 13 * TILESIZEY + 4*13 )
			{ // fade in-out
				unpackLogoTiles( (logoAnim - 13 * TILESIZEY + 1) >> 2, 0);
			}
			else if (logoAnim == 13 * TILESIZEY + 4 * 13 + 57 )
			{
				// The following "goToGame();" line is uncommented only for game debug! Leave it commented!
				//goToGame();
				// clear logo tiles
				memset(&tiles[NUMBER_OF_CHARACTERS], 0, sizeof(tiles[0]) * (MAX_TILES - NUMBER_OF_CHARACTERS));
				memset(vram,0, sizeof(vram));
				// restore the 1:1 row remapping
				for (int i = 0; i < 200; i++)
					rowRemapTable[i] = i;
				drawMenu(0, 0, 1);
			}
			else if (logoAnim > 13 * TILESIZEY + 4 * 13 + 57 )
			{
				logoAnim = 253;		// put any number larger than the previous case, but smaller than 255.
				uint8_t oldPage = currentPage;
				uint16_t key = keyBuffer[0];
				uint8_t redrawRequired = 0;
				if (oldKey != key)
				 {
					if (EXBUFF_TO_OEM(key) == USB_KEY_DOWN)
					{			
						redrawRequired = 1;		
						selectedFile++;
						// let's see if there are more files.
						if (selectedFile >= numberOfFiles)
						{
							// go back to page 0
							selectedFile = 0;
						}
					}
					else if (EXBUFF_TO_OEM(key) == USB_KEY_UP)
					{
						redrawRequired = 1;
						if (selectedFile > 0)
						{
							selectedFile--;
						}
						else
						{
							selectedFile = max(0, numberOfFiles - 1);
						}
					}
					else if (key == '\r' && binLength)
					{
						redrawRequired = 1;
						// first do we need to program the file? calculate the checksum and see if there is something to do.
						uint32_t *p = (uint32_t*) GAME_START_ADDRESS;
						uint32_t checksum = 0;
						for (int i = 0; i < binLength/4; i++)
						{
							checksum += *p++;
						}
						if (checksum != binChecksum)
						{
							// different game loaded. Erase and write.
							memset(vram, 0, sizeof(vram));
							printLine ("Erasing...", 10,10);
							// 
							for (int i = 0; i < 6; i++)
							{
								uint8_t color = colors[i];
// 								if (i < 2)	// regions that won't be programmed
// 									color = COLOR_TORGB332(7, 5, 1);
// 								else if (i < 4)	// erased region
// 									color = COLOR_TORGB332( 0, 5, 3);
// 								else  //  programmed region
// 									color = COLOR_TORGB332( 1, 5, 1);
								putCharInTile(NULL,132 + (i & 1), color,0,0, (uint8_t*) &tiles[NUMBER_OF_CHARACTERS + i - 2], 0);	
							}
							// bottom and top border
							for (int x = 3; x < 35; x++)
							{
								const uint8_t tv [] = {130 - ' ', 132 - ' ' , 133 - ' ',  131 - ' '};
								for (int i = 11; i <= 14; i++)
								{
									vram[x + i * VRAMX] = tv[i - 11];
								}
							}
							for (int y = 12; y < 14; y++)
							{
								vram[2 + y * VRAMX] = 128 - ' ';
								vram[35 + y * VRAMX] = 129 - ' ';								
							}
							// 
							erase(GAME_START_ADDRESS, binLength + GAME_START_ADDRESS);
							printLine ("Programming...", 10,10);
 							// erased. Now write program. The file was already open and selected. Therefore 
							uint32_t address = GAME_START_ADDRESS;
							UINT br; 
							while(binLength)
							{
								uint32_t remainingLength = binLength;
								if (remainingLength > 512)
									remainingLength = 512;
								pf_read(fileBuffer, remainingLength, &br);
								writeToFlash(fileBuffer, address, remainingLength);
								int x = 3 + (address >> 13);
								vram[x + 12 * VRAMX] = NUMBER_OF_CHARACTERS + 2;
								vram[x + 13 * VRAMX] = NUMBER_OF_CHARACTERS + 3;
								address += remainingLength;
								binLength -= remainingLength;
							}
						}
						goToGame();
					}
				}
				currentPage = selectedFile / FILES_PER_PAGE;
				if (redrawRequired)
				{
					bootloaderStartSong(menuSound);
					drawMenu(currentPage, selectedFile % FILES_PER_PAGE, oldPage != currentPage);				
				}
				oldKey = key; 
			}
			logoAnim++;
		}
		setLed(g_frame & 32);
		g_frame++;
		do
		{
			// Note! In bootloader, to save us from checking twice if the keyboard or gamepad are installed, the poll command is queued AFTER the usbHostTask is executed
			// However, since we are performing a loop, except the very first cycle after enumeration, there always be good data.
			#if !NO_USB
			usbHostTask();
			if (usbHidBootKeyboardIsInstalled())
			{
				usbKeyboardPoll();
				usbGetCurrentAsciiKeyboardStateEx(keyBuffer);
			}			
			if (usbHidGenericGamepadIsInstalled())
			{
				gamePadState_t gps;
				usbHidGenericGamepadPoll();
				// gamepad to keyboard conversion
				getCurrentGamepadState(&gps);
				keyBuffer[0] = 0;
				if (gps.axes[1] == gps.XYZRxMinimum)
				{

					if (gps.buttons == (GP_BUTTON_R1 | GP_BUTTON_L1 | GP_BUTTON_L2 | GP_BUTTON_R2))
						keyBuffer[0] = USB_KEY_RESET;
					else
						keyBuffer[0] = USB_KEY_UP << 8;
				}
				else if (gps.axes[1] == gps.XYZRxMaximum)
					keyBuffer[0] = USB_KEY_DOWN << 8;
				if (gps.buttons & (GP_BUTTON_1 | GP_BUTTON_2 | GP_BUTTON_3 | GP_BUTTON_4))
					keyBuffer[0] = '\r';						
			}
			if (keyBuffer[0] == USB_KEY_RESET)
			{  //  reset.
				SCB->AIRCR  = ((0x5FAUL << SCB_AIRCR_VECTKEY_Pos) |  SCB_AIRCR_SYSRESETREQ_Msk); 
				while(1);
			}
			#endif
		} while (getCurrentScanLineNumber() < 523); 
	}
}

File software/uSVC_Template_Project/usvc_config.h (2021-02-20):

/*
 *  USVC Template Project
 *
 *  Change/remove this copyright part when you create your own program!
 * 
 *  Copyright 2019-2020 Nicola Wrachien (next-hack.com)
 *
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
 *  tl;dr 
 *  Do whatever you want, this program is free! Though we won't 
 *  reject donations https://next-hack.com/index.php/donate/ :) 
 *
 */
#ifndef USVC_CONFIG_H_
#define USVC_CONFIG_H_
#include <stdint.h>
// Graphics mode definition. TILE_MODE1 = 8bpp (256 colors). TILE_MODE2 = 4bpp (16 colors). BITMAPPED_MODE: 2 bit per pixels
#define GFX_MODE TILE_MODE1
// For TILE_MODE2 and TILE_MODE1 you can redefine VRAMX and VRAMY. Minimum values are VRAM = 40 and VRAMY = 25
#if GFX_MODE == TILE_MODE2 || GFX_MODE == TILE_MODE1
// note: if using meta tiles, vramy and vramx size should be a multiple of 2.
	#define VRAMX 40
	#define VRAMY 25	
	// Max number of tiles. Note that this number must include both the number of Ram Tile, and the number of temporary sprite tiles. 
	#define MAX_TILES (100)  // adjust this according to the number of tiles
#endif
// sprites (only for TILE_MODE1 and TILE_MODE2). Adjust everything according to your requirements
#define SPRITES_ENABLED 0
#define ENABLE_TRANSPARENT_SPRITES  0	// only for TILE_MODE1. Require to include a file, which defines a variable transparentSpriteColorTable.
#define MAX_TEMP_SPRITE_TILES 100		// Be sure to set also MAX_TILES large enough!
#define MAX_ONSCREEN_SPRITES 16			// Number of actual sprites on screen
#define ENABLE_SPRITE_PRIORITY 0        // if 1, it is possible to put the sprite always on top of a tile (regardless its priority) or always under the tiles.
// Tile priority
#define ENABLE_TILE_PRIORITY 0			// if 1, it is possible to define the priority of a tile, so that it will appear on top of those sprites without top or bottom priority
#define TILES_ALL_OPAQUE 1				// (used only if ENABLE_TILE_PRIORITY is 1) if 1, it tells the engine that all the tiles are either completely transparent or completely opaque, so that, if they have priority, the sprite won't appear under them.
// Advanced video features:
// number of palettes (only for tile mode 2 or bitmapped mode)
#define MAX_NUMBER_OF_PALETTES 2	// each palette has 256 entries. Each entry is 4 bytes, so use it carefully!
// Color Change Engine (only for TILE_MODE2)
#define ENABLE_PALETTE_REMAPPING 0					// if 1, enables the color change engine, allowing to change palette on each row.
#define ENABLE_PER_LINE_COLOR_REMAPPING 0			// if 1 it also allows to change an arbitrary color index for one particular palette, on each row.
#define ENABLE_HIRES_PER_LINE_COLOR_REMAPPING 0		// if 1, each table entry is interpreted as a single hires row (400 rows). If 0, each entry is for 2 hires row.
#define ENABLE_PALETTE_ROW_REMAPPING 0				// Advanced: if 1, allows to add for each line, an offset, so that the actual table row accessed will be offset[Row] + row;
// ROW Remapping: allows to arbitrarily replace the vertical line position.
#define USE_ROW_REMAPPING 0							// if 1 enables vertical remapping.	
#define USE_HIRES_ROW_REMAPPING 1					// (only for TILE_MODE2) if 1 remapping occurs on hi-res basis. Note that in this case, the entry only point to low-res lines. 
// Horizontal scroll.
#define PER_LINE_X_SCROLL 0							// if 1, scroll can be specified on per line basis (screen relative! - before any rowRemapping)
#define PER_TILE_X_SCROLL 0							// if 1, scroll can be specified on per tile basis (vram relative! - after any rowRemapping!)
/*
	FIXED SECTION
	TILE_MODE1 and TILE_MODE2 allow for a fixed section (no-scroll) at the top or bottom of the screen.
	To activate it: 
	define USE_SECTION as TOP_FIXED_SECTION or BOTTOM_FIXED_SECTION
	eg, for a bottom fixed section:
	#define USE_SECTION TOP_FIXED_SECTION
	Also set the section limit, i.e. the row at which the section starts (for bottom) or ends (for top). The number is in terms of tiles and it is not inclusive.
*/
#define USE_SECTION NO_FIXED_SECTION
#define SECTION_LIMIT 2
#define USE_SEPARATE_FIXED_SECTION_PALETTE 0		// Only for TILE_MODE2: the fixed section has its own palette 
#define FIXED_SECTION_PALETTE_INDEX 0				// Only for TILE_MODE2 and if USE_SEPARATE_FIXED_SECTION_PALETTE is 1: palette of the fixed section
#define FIXED_SECTION_MAPSIZEX 40					// width of fixed section map. It must be 40!
#define FIXED_SECTION_MAPSIZEY 3					// height of fixed section map.
#define MAX_FIXED_SECTION_TILES 16					// number of separated tiles for the fixed section.
#if USE_SECTION != NO_FIXED_SECTION
	extern uint32_t fixedSectionTiles[MAX_FIXED_SECTION_TILES][GFX_MODE == TILE_MODE2 ? 8 : 16] __attribute__ ((aligned (4)));
	extern uint8_t fixedSectionMap[FIXED_SECTION_MAPSIZEX * FIXED_SECTION_MAPSIZEY]  __attribute__ ((aligned (4)));
#endif
/* AUDIO.
	Audio is made of two modules. The sound Engine, and the Audio Mixer.
	The sound Engine is a port of Alec Borque's UZEBox sound engine, with minor changes, and it provides support for samples and songs.
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

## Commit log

2020-06-18 Added schematics in pdf format
2020-06-18 updated fine print.
    [uChipVGA2V1.sch]
2020-11-22 Improved USB power handling
    Improved USB power handling technique
2020-12-08 Fixed Audio Engine Bug, added game loader and demos
    Fixed a bug for which a channel used for sound fx could not be used anymore for a regular note, for patchless fx.
    Added demos, ad game loader.
    [audio.h]
2020-12-12 triggerFx now can detune sample and force channel usage.
2021-02-20 Fixed bug on setSongSpeed()
    [audio.h, usvc_config.h]
2021-02-20 Fixed setSongSpeed() bug on all projects
    [audio.h]

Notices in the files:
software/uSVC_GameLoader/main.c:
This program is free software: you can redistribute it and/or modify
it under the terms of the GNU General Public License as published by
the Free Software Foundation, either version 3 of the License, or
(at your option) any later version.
